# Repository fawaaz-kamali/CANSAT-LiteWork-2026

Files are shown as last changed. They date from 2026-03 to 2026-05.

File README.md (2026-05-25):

# CANSAT-LiteWork-2026
Repository containing major program files and schematics for Team 'Lite Work for the TMU CANSAT STEC Initiative 

Team Members: Fawaaz Kamali Siddiqui, Ben Reboks, Basim Allawala, Hamid Karimi, Mohammad Alwattar

## ESP32 Flight Computer

### Overview

The flight computer designed in the PDR phase of the competition is simply named the ESP32 Flight Computer. The circuit was designed 
entirely in KiCad and the microcontroller for the circuit is the ESP32-S3-WROOM-1. 

The parts list for this circuit is as follows:

| Model | Description |
|---|---|
| ESP32-S3-WROOM-1 | Microcontroller Unit |
| ICM-42670-L | Inertial Measurement Unit |
| ICP-20100 | Barometric Pressure Sensor |
| NEO-6M Breakout Board | GPS Module |
| 2 x SG90 | Servo Motors |
| 1S 18605 LiFePO4 | Battery |

#### KiCad Files
<div align="center">
  <div>
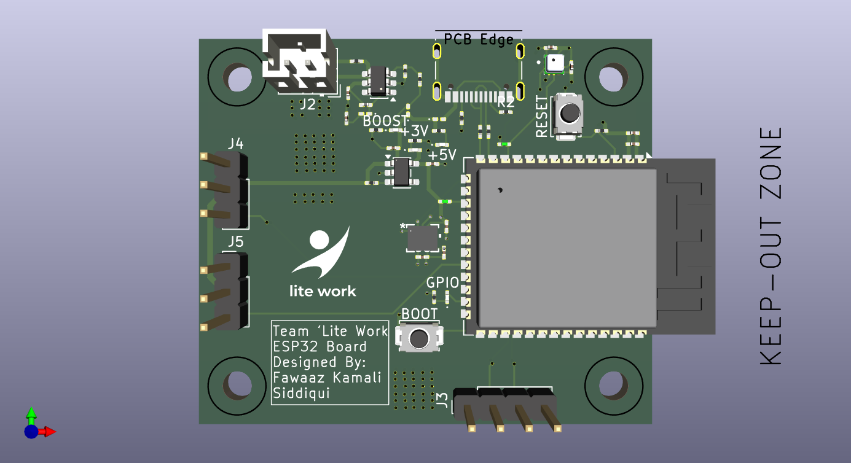
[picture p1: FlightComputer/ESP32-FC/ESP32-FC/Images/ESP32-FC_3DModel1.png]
    
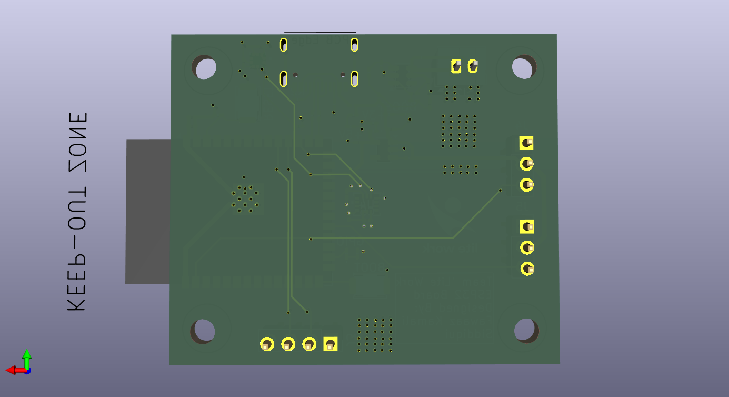
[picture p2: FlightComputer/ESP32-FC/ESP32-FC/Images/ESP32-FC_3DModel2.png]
    
    <p><em>3D Render</em></p>
  </div>
  <br>

  <div>
    Schematic<br>
    <p><em>Schematic</em></p>
  </div>
  <br>
  
  <div>
    Front
    Back<br>
    <em>Footprint</em>
  </div>
</div>

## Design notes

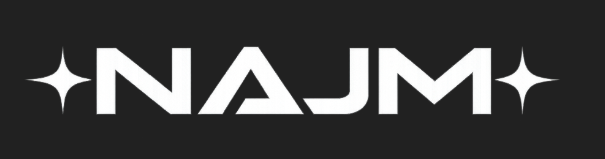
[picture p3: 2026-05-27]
FlightComputer/Arduino-FC/Arduino-FC/Images/Najm.png

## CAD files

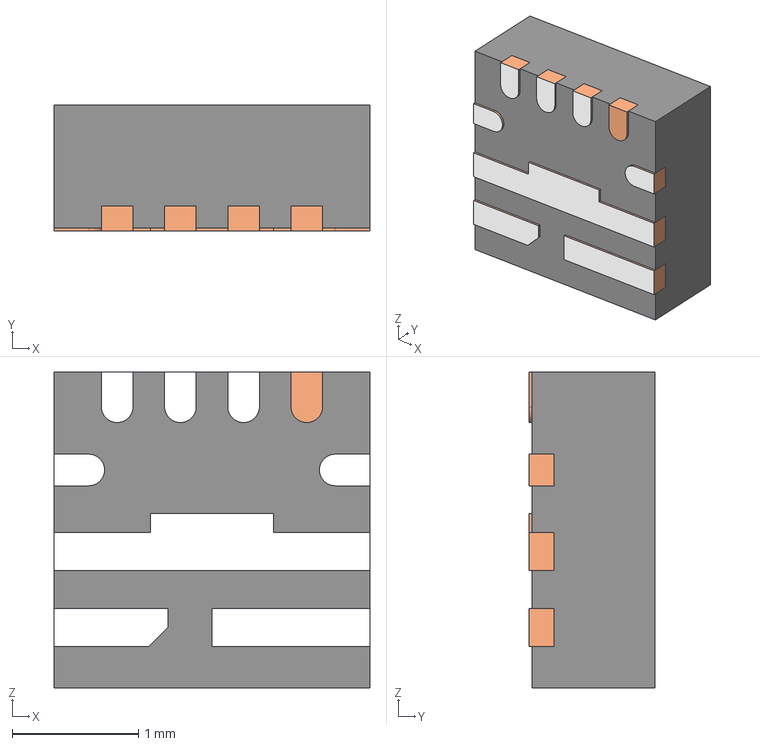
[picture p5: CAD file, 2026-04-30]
FlightComputer/Arduino-FC/Arduino-FC/TPS61236P/RWL0009A.stp
2.50 x 1.00 x 2.50 mm
FRAME-RWL0009A
BODY-QFN

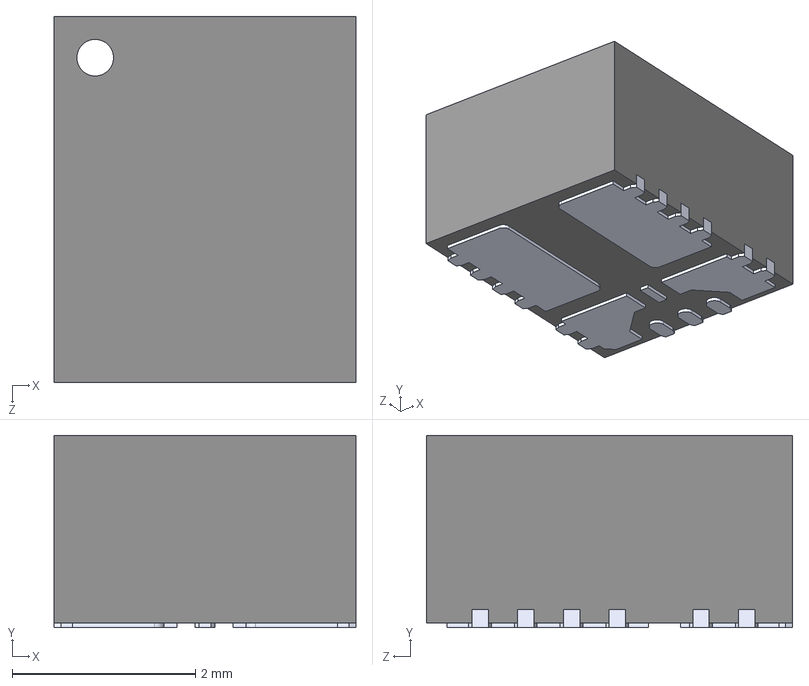
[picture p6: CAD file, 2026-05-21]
FlightComputer/Arduino-FC/Arduino-FC/TPSM863252RDXR/TPSM863252RDXR.step
3.30 x 2.10 x 4.00 mm

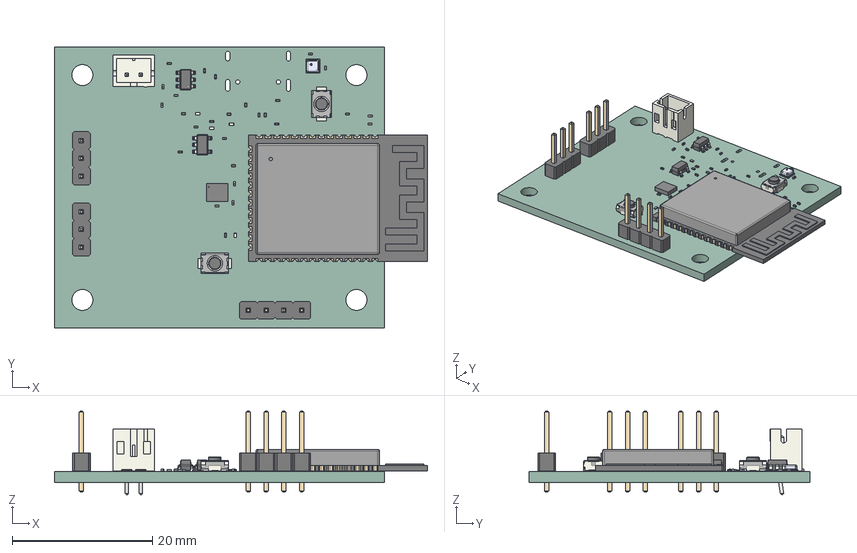
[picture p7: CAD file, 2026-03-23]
FlightComputer/ESP32-FC/ESP32-FC/ESP32-FC.step
53.2 x 40.0 x 11.9 mm
R_0201_0603Metric x 15
SW_Push_SPST_NO_Alps_SKRK x 2
LGA14_2_5X3X0_76_IVS
L_0201_0603Metric
C_0201_0603Metric x 11
ESP32-S3-WROOM-1
JST_PH_B2B-PH-K_1x02_P2.00mm_Vertical
LED_0201_0603Metric x 4
SOT-23-5
SOT-23-6
PinHeader_1x03_P2.54mm_Vertical x 2
ICP-20100
PinHeader_1x04_P2.54mm_Vertical
ESP32-FC_PCB

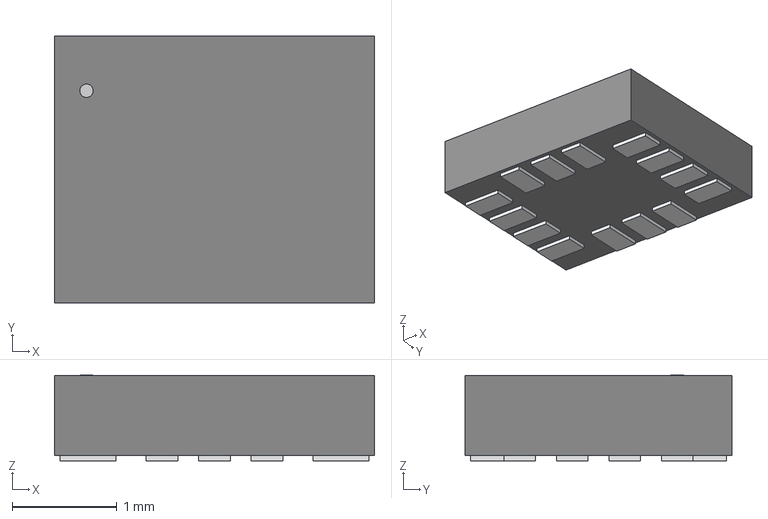
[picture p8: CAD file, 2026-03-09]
FlightComputer/ESP32-FC/ESP32-FC/ICM-42670-L/LGA14_2_5X3X0_76_IVS.step
3.05 x 2.54 x 0.815 mm

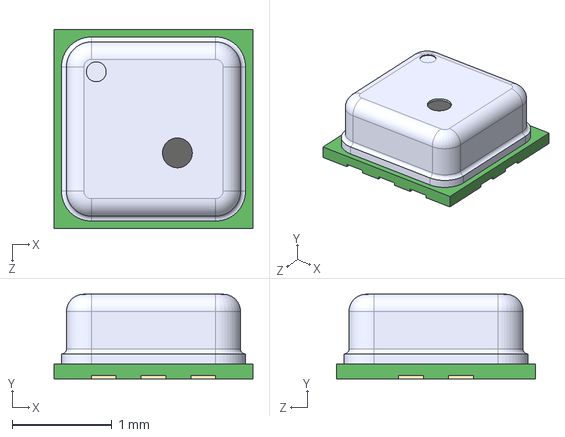
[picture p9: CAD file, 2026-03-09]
FlightComputer/ESP32-FC/ESP32-FC/ICP-20100/ICP-20100.step
2.00 x 0.85 x 2.00 mm

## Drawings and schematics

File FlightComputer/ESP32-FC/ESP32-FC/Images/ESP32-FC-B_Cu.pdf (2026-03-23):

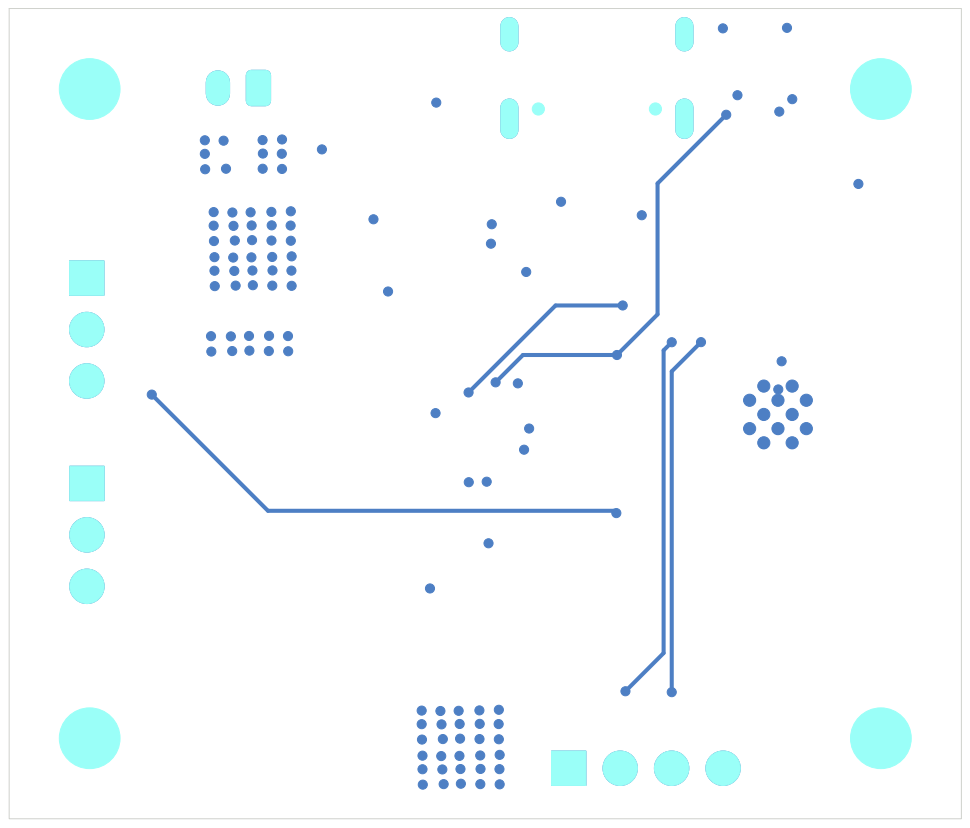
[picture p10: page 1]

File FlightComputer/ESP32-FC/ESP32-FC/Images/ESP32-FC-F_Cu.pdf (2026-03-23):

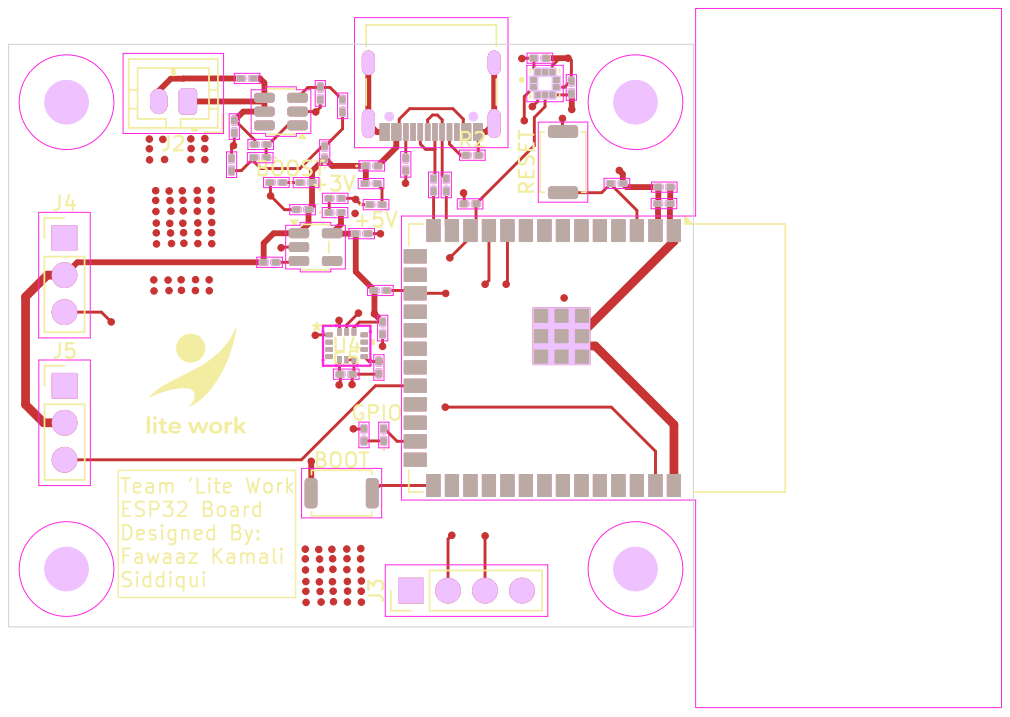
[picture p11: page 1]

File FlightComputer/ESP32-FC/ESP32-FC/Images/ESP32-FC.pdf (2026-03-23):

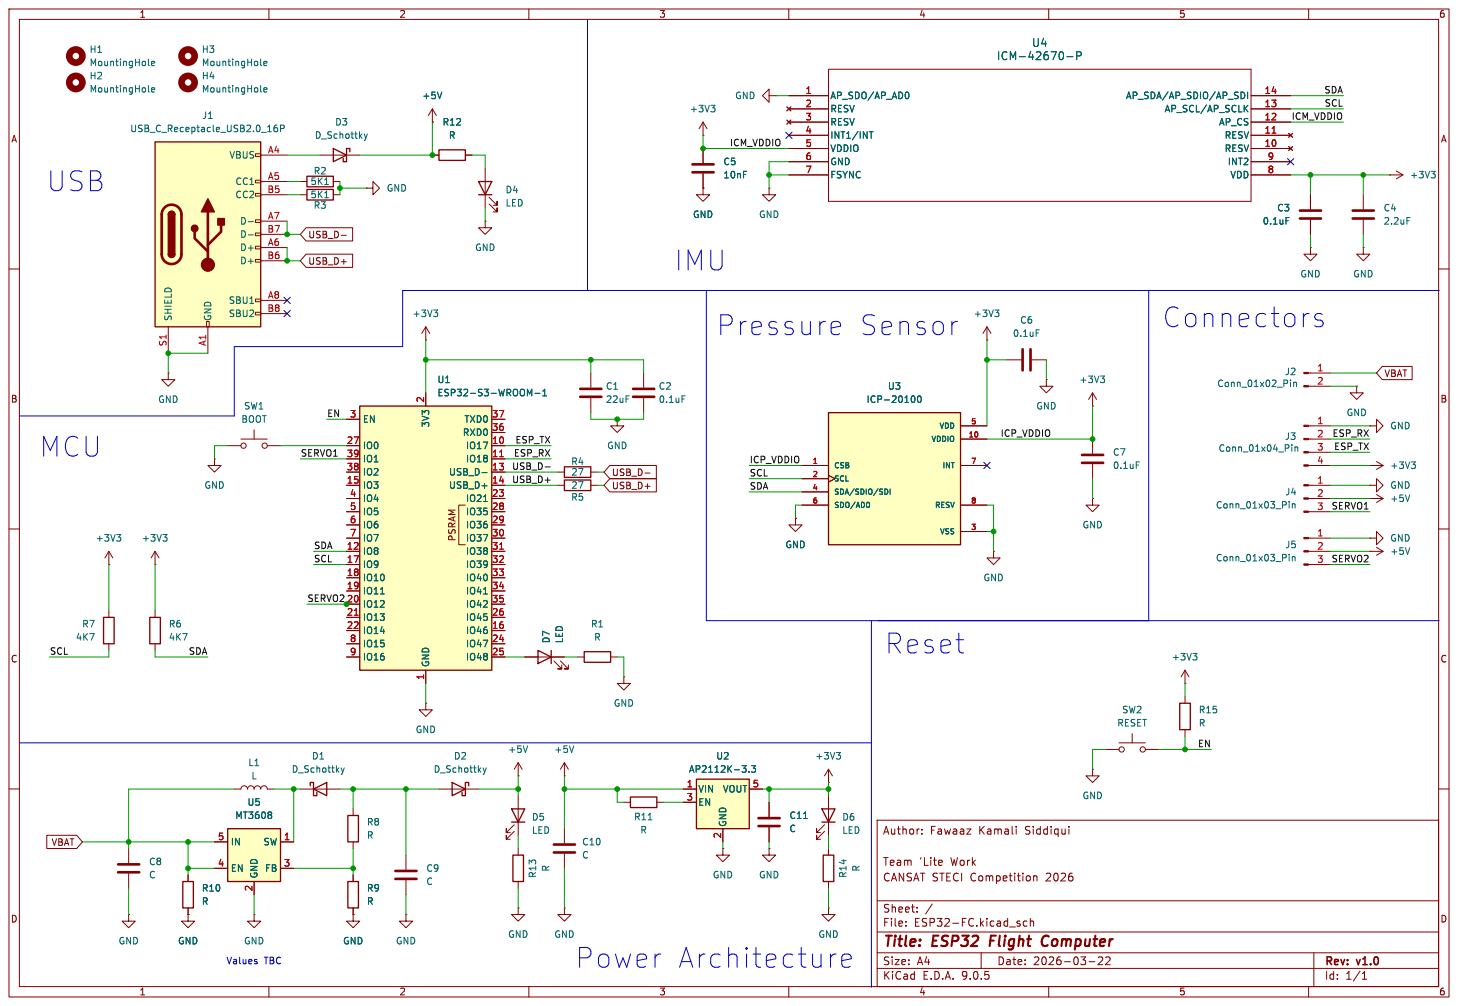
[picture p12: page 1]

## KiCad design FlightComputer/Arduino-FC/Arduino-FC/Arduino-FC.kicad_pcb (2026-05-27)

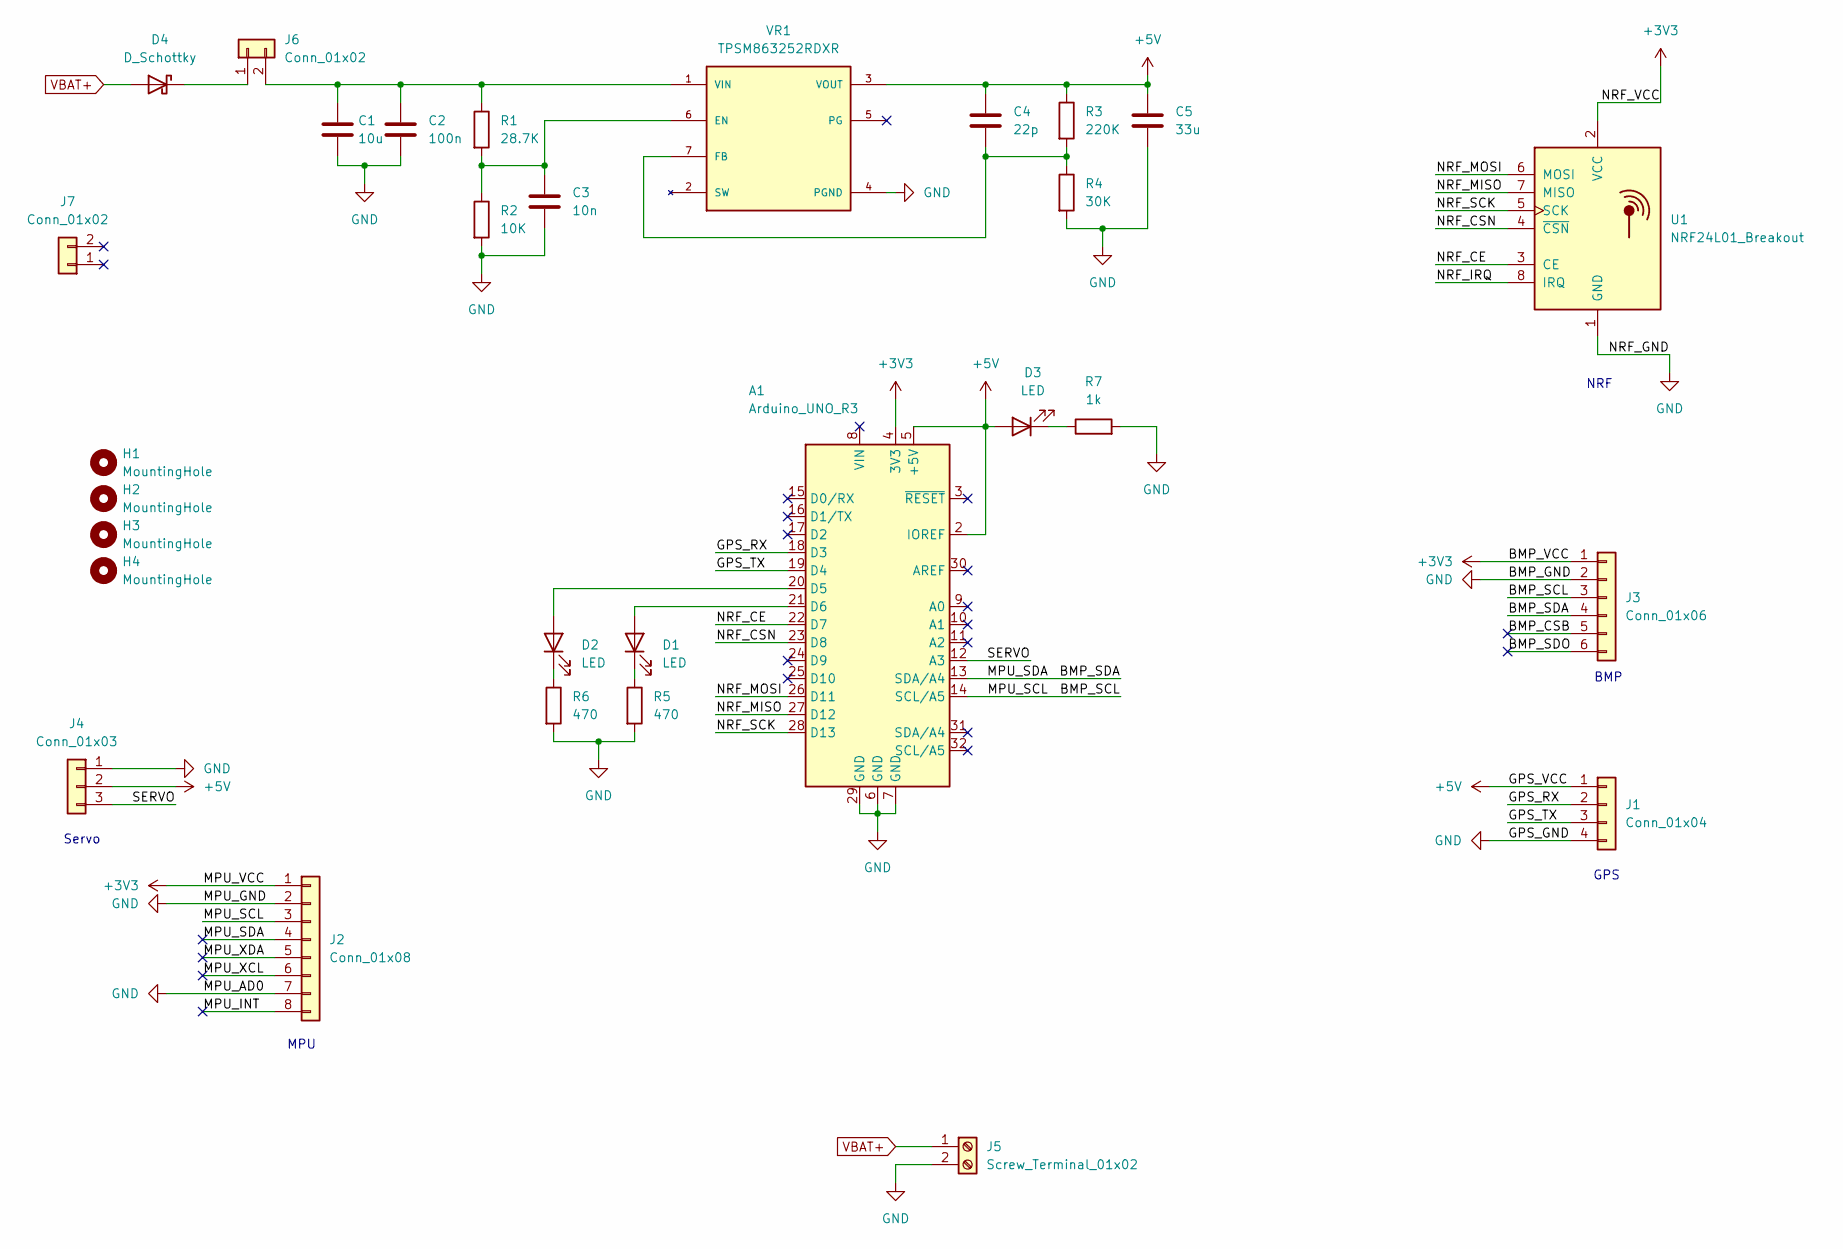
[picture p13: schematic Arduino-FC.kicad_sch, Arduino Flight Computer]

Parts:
A1: Arduino_UNO_R3
C1: 10u; C_0805_2012Metric_Pad1.18x1.45mm_HandSolder
C2: 100n; C_0805_2012Metric_Pad1.18x1.45mm_HandSolder
C3: 10n; C_0402_1005Metric_Pad0.74x0.62mm_HandSolder
C4: 22p; C_0402_1005Metric_Pad0.74x0.62mm_HandSolder
C5: 33u; C_1812_4532Metric_Pad1.57x3.40mm_HandSolder
D1, D2, D3: LED; LED_D5.0mm_Clear
D4: D_Schottky; DO-214AC
H1, H2, H3, H4: MountingHole; MountingHole_2.2mm_M2
J1: Conn_01x04; PinHeader_1x04_P2.54mm_Vertical
J2: Conn_01x08; PinHeader_1x08_P2.54mm_Vertical
J3: Conn_01x06; PinHeader_1x06_P2.54mm_Vertical
J4: Conn_01x03; PinHeader_1x03_P2.54mm_Vertical
J5: Screw_Terminal_01x02; TerminalBlock_MaiXu_MX126-5.0-02P_1x02_P5.00mm; LCSC C8465
J6, J7: Conn_01x02; PinHeader_1x02_P2.54mm_Vertical
R1: 28.7K; R_0402_1005Metric_Pad0.72x0.64mm_HandSolder
R2: 10K; R_0402_1005Metric_Pad0.72x0.64mm_HandSolder
R3: 220K; R_0603_1608Metric_Pad0.98x0.95mm_HandSolder
R4: 30K; R_0603_1608Metric_Pad0.98x0.95mm_HandSolder
R5, R6: 470; R_Axial_DIN0414_L11.9mm_D4.5mm_P15.24mm_Horizontal
R7: 1k; R_Axial_DIN0414_L11.9mm_D4.5mm_P15.24mm_Horizontal
U1: NRF24L01_Breakout; nRF24L01-Adapter
VR1: TPSM863252RDXR; VREG_TPSM863252RDXR; PARTREV B

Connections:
+3V3: A1.4 (3V3), J2.1, J3.1, U1.2 (VCC)
+5V: A1.2 (IOREF), A1.5 (+5V), C4.1, C5.1, D3.2 (A), J1.1, J4.2, R3.1, VR1.3 (VOUT)
/BMP_CSB: J3.5
/BMP_SCL: A1.14 (SCL/A5), J2.3, J3.3
/BMP_SDA: A1.13 (SDA/A4), J2.4, J3.4
/BMP_SDO: J3.6
/GPS_RX: A1.18 (D3), J1.2
/GPS_TX: A1.19 (D4), J1.3
/MPU_INT: J2.8
/MPU_XCL: J2.6
/MPU_XDA: J2.5
/NRF_CE: A1.22 (D7), U1.3 (CE)
/NRF_CSN: A1.23 (D8), U1.4 (~CSN)
/NRF_IRQ: U1.8 (IRQ)
/NRF_MISO: A1.27 (D12), U1.7 (MISO)
/NRF_MOSI: A1.26 (D11), U1.6 (MOSI)
/NRF_SCK: A1.28 (D13), U1.5 (SCK)
/SERVO: A1.12 (A3), J4.3
GND: A1.6 (GND), A1.7 (GND), A1.29 (GND), C1.2, C2.2, C3.2, C5.2, J1.4, J2.2, J2.7, J3.2, J4.1, J5.2, R2.2, R4.2, R5.2, R6.2, R7.2, U1.1 (GND), VR1.4 (PGND)
unnamed: A1.20 (D5), D2.2 (A)
unnamed: A1.21 (D6), D1.2 (A)
unnamed: D1.1 (K), R5.1
unnamed: D2.1 (K), R6.1
unnamed: D3.1 (K), R7.1
unnamed: D4.1 (K), J6.1
unnamed: C1.1, C2.1, J6.2, R1.1, VR1.1 (VIN)
unnamed: C3.1, R1.2, R2.1, VR1.6 (EN)
unnamed: C4.2, R3.2, R4.1, VR1.7 (FB)
VBAT+: D4.2 (A), J5.1

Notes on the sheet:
GPS
NRF
Servo
BMP
MPU

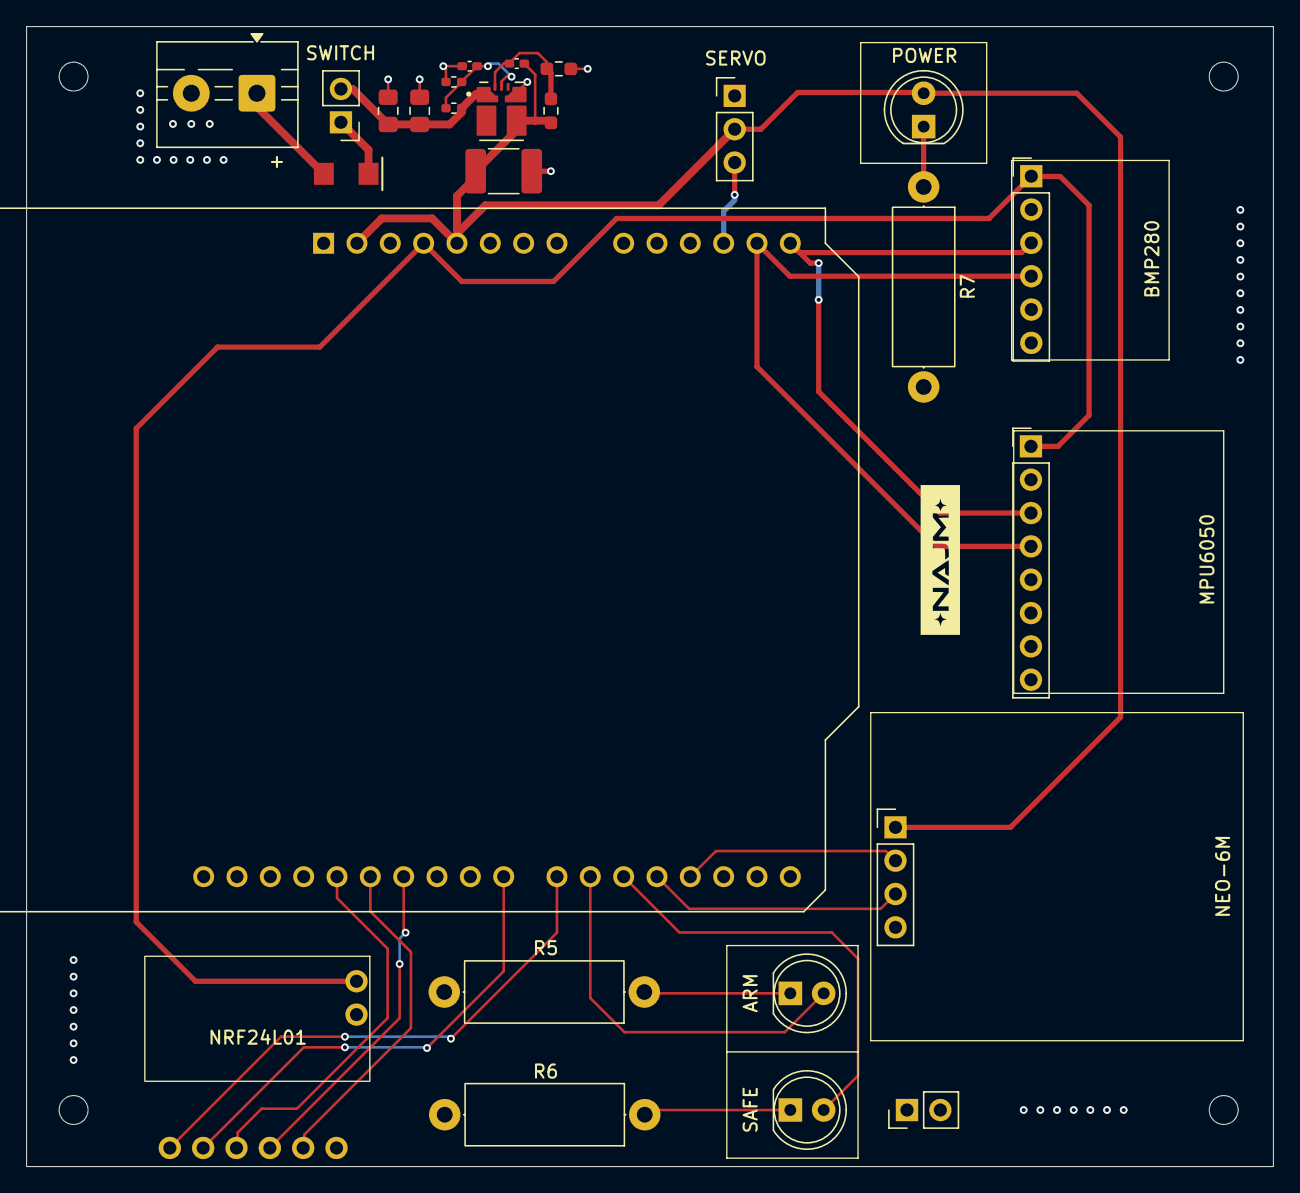
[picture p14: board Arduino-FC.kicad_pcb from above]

Board: 2 copper layers, 95.0 x 86.9 mm, 30 parts (0 on the bottom side), 23 nets.

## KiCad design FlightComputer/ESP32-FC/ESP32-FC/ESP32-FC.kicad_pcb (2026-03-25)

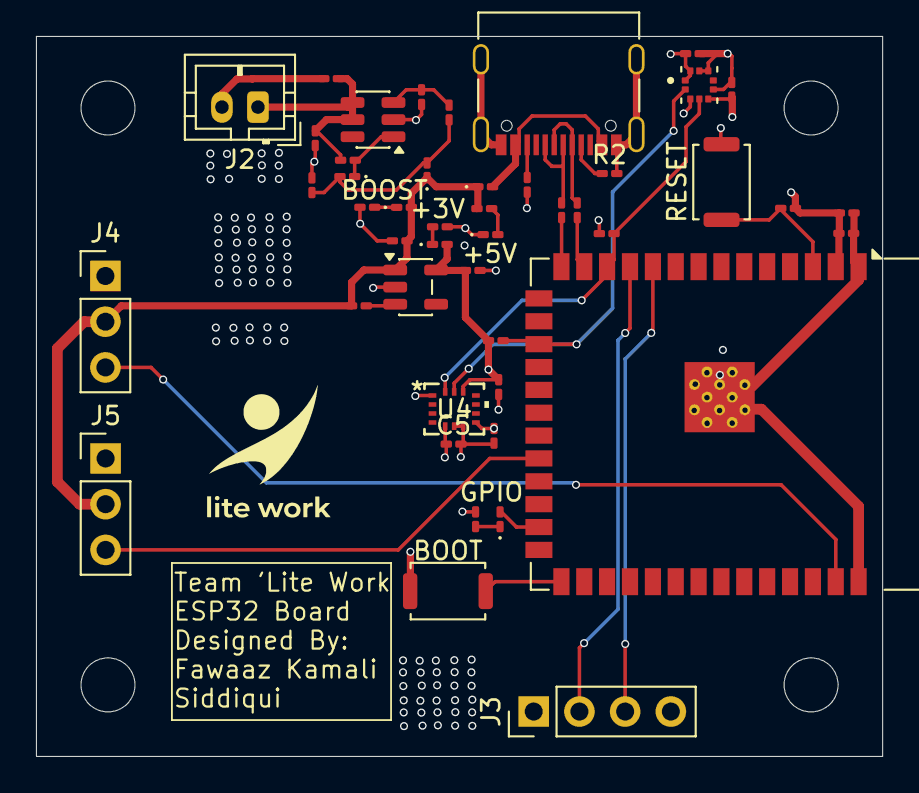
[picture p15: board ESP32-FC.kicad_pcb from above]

Board: 4 copper layers, 47.0 x 40.0 mm, 50 parts (0 on the bottom side), 26 nets.

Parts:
+3V, +5V: LED; LED_0201_0603Metric_Pad0.64x0.40mm_HandSolder
BOOST: LED; LED_0201_0603Metric_Pad0.64x0.40mm_HandSolder
BOOT: BOOT; SW_Push_SPST_NO_Alps_SKRK
C1: 22uF; C_0201_0603Metric_Pad0.64x0.40mm_HandSolder
C2, C3, C6, C7: 0.1uF; C_0201_0603Metric_Pad0.64x0.40mm_HandSolder
C4: 2.2uF; C_0201_0603Metric_Pad0.64x0.40mm_HandSolder
C5: 10nF; C_0201_0603Metric_Pad0.64x0.40mm_HandSolder
C8, C9, C10, C11: C; C_0201_0603Metric_Pad0.64x0.40mm_HandSolder
D1, D2, D3: D_Schottky; D_0201_0603Metric_Pad0.64x0.40mm_HandSolder
GPIO: LED; LED_0201_0603Metric_Pad0.64x0.40mm_HandSolder
H1, H2, H3, H4: MountingHole; MountingHole_3mm
J1: USB_C_Receptacle_USB2.0_16P; USB_C_Receptacle_Palconn_UTC16-G
J2: Conn_01x02_Pin; JST_PH_B2B-PH-K_1x02_P2.00mm_Vertical
J3: Conn_01x04_Pin; PinHeader_1x04_P2.54mm_Vertical
J4, J5: Conn_01x03_Pin; PinHeader_1x03_P2.54mm_Vertical
L1: L; L_0201_0603Metric_Pad0.64x0.40mm_HandSolder
R1, R8, R9, R10, R11, R12, R13, R14, R15: R; R_0201_0603Metric_Pad0.64x0.40mm_HandSolder
R2, R3: 5K1; R_0201_0603Metric_Pad0.64x0.40mm_HandSolder
R4, R5: 27; R_0201_0603Metric_Pad0.64x0.40mm_HandSolder
R6, R7: 4K7; R_0201_0603Metric_Pad0.64x0.40mm_HandSolder
RESET: RESET; SW_Push_SPST_NO_Alps_SKRK
U1: ESP32-S3-WROOM-1
U2: AP2112K-3.3; SOT-23-5
U3: ICP-20100; PQFN50P200X200X85-10N
U4: ICM-42670-P; LGA14_2.5X3X0.76_IVS-L
U5: MT3608; SOT-23-6

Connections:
+3V3: +3V.2 (A), C1.1, C2.1, C3.1, C4.1, C5.1, C6.2, C7.1, C11.1, J3.4, R6.1, R7.1, R15.1, U1.2 (3V3), U2.5 (VOUT), U3.1 (CSB), U3.5 (VDD), U3.10 (VDDIO), U4.5 (VDDIO), U4.8 (VDD), U4.12 (AP_CS)
+5V: BOOST.2 (A), C10.1, D2.1 (K), D3.1 (K), J4.2, J5.2, R11.1, R12.1, U2.1 (VIN)
/EN: R15.2, RESET.2, U1.3 (EN)
/ESP_RX: J3.2, U1.11 (IO18)
/ESP_TX: J3.3, U1.10 (IO17)
/SCL: R7.2, U1.17 (IO9), U3.2 (SCL), U4.13 (AP_SCL/AP_SCLK)
/SDA: R6.2, U1.12 (IO8), U3.4 (SDA/SDIO/SDI), U4.14 (AP_SDA/AP_SDIO/AP_SDI)
/SERVO1: J4.3, U1.39 (IO1)
/SERVO2: J5.3, U1.22 (IO14)
GND: +5V.1 (K), BOOT.1, C1.2, C2.2, C3.2, C4.2, C5.2, C6.1, C7.2, C8.2, C9.2, C10.2, C11.2, J1.A1 (GND), J1.A12 (GND), J1.B1 (GND), J1.B12 (GND), J1.S1 (SHIELD), J2.2, J3.1, J4.1, J5.1, R1.2, R2.2, R3.2, R9.2, R10.2, R13.1, R14.1, RESET.1, U1.1 (GND), U1.40 (GND), U1.41 (GND), U2.2 (GND), U3.3 (VSS), U3.6 (SDO/AD0), U3.8 (RESV), U3.9 (RESV), U4.1 (AP_SDO/AP_AD0), U4.6 (GND), U4.7 (FSYNC), U5.2 (GND)
unnamed: C9.1, D1.2 (A), D2.2 (A), R8.1
unnamed: D1.1 (K), L1.2, U5.1 (SW)
unnamed: D3.2 (A), J1.A4 (VBUS), J1.A9 (VBUS), J1.B4 (VBUS), J1.B9 (VBUS)
unnamed: +5V.2 (A), R12.2
unnamed: BOOST.1 (K), R13.2
unnamed: +3V.1 (K), R14.2
unnamed: GPIO.2 (A), U1.25 (IO48)
unnamed: GPIO.1 (K), R1.1
unnamed: J1.A5 (CC1), R2.1
unnamed: J1.B5 (CC2), R3.1
unnamed: BOOT.2, U1.27 (IO0)
unnamed: R11.2, U2.3 (EN)
unnamed: R8.2, R9.1, U5.3 (FB)
USB_D+: J1.A6 (D+), J1.B6 (D+), R5.1, R5.2, U1.14 (USB_D+)
USB_D-: J1.A7 (D-), J1.B7 (D-), R4.1, R4.2, U1.13 (USB_D-)
VBAT: C8.1, J2.1, L1.1, R10.1, U5.4 (EN), U5.5 (IN)

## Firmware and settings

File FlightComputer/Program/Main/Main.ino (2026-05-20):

/*
 * Rui Santos 
 * Complete Project Details https://randomnerdtutorials.com
 */
 
#include <SoftwareSerial.h>

// The serial connection to the GPS module
SoftwareSerial ss(4, 3);

void setup(){
  Serial.begin(9600);
  ss.begin(9600);
}

void loop(){
  while (ss.available() > 0){
    // get the byte data from the GPS
    byte gpsData = ss.read();
    Serial.write(gpsData);
  }
}

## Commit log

2026-03-08 Project Initialization
    [ESP32-FC.kicad_pcb, ESP32-FC.kicad_sch]
2026-03-08 Added USB Connection
    [ESP32-FC.kicad_sch]
2026-03-08 Added MPU
    [ESP32-FC.kicad_sch]
2026-03-09 Addd ICM
    - Removed MPU 6050
    - Added ICM-42670-P
    [ESP32-FC.kicad_sch, LGA14_2_5X3X0_76_IVS.step]
2026-03-09 Added ICP
    - Added pressure sensor module
    [ESP32-FC.kicad_sch, ICP-20100.step]
2026-03-19 Layout Creation
    [ESP32-FC.kicad_pcb, ESP32-FC.kicad_sch]
2026-03-22 Updated power architecture
    [ESP32-FC.kicad_sch]
2026-03-22 Servo + LEDs
    [ESP32-FC.kicad_sch]
2026-03-22 Boot Config
    [ESP32-FC.kicad_sch]
2026-03-22 Part placement
    [ESP32-FC.kicad_pcb, ESP32-FC.kicad_sch]
2026-03-23 Layout Major
    [ESP32-FC.kicad_pcb]
2026-03-23 Export STEP file
    [ESP32-FC.step]
2026-03-23 Update schematic
    [ESP32-FC.kicad_sch]
2026-03-23 Schematic Plot
2026-03-23 3D model images
    [ESP32-FC.kicad_pcb]
2026-03-23 Enhance README with PCB 3D model image
    TODO:
    > Add svg image of schematic and layout
2026-03-25 Added Images
    [ESP32-FC.kicad_pcb]
2026-03-25 Update README
    Added team members and detailed overview of the ESP32 Flight Computer, including parts list and KiCad files.
2026-04-30 Added second FC
    [Arduino-FC.kicad_pcb, Arduino-FC.kicad_sch, RWL0009A.stp]
2026-05-20 Added Main.ino
    Updated schematic connections
    [Arduino-FC.kicad_sch]
2026-05-21 Buck Converter
    Footprint assignments
    [Arduino-FC.kicad_sch, TPSM863252RDXR.step]
2026-05-24 Layout created
    [Arduino-FC.kicad_pcb]
2026-05-25 Custom NRF Adapter footprint
    [Arduino-FC.kicad_pcb, Arduino-FC.kicad_sch]
2026-05-25 Indicator LEDs + Screw terminal
    [Arduino-FC.kicad_pcb, Arduino-FC.kicad_sch]
2026-05-25 Added switch
    [Arduino-FC.kicad_pcb, Arduino-FC.kicad_sch]
2026-05-26 Buck Converter Updates
    - updated footprint + values
    [Arduino-FC.kicad_sch]
2026-05-26 Diode + Power Jumper
    [Arduino-FC.kicad_pcb, Arduino-FC.kicad_sch]
2026-05-26 Mounting Holes Added
    [Arduino-FC.kicad_pcb, Arduino-FC.kicad_sch]
2026-05-26 Design Constraints
    [Arduino-FC.kicad_pcb]
2026-05-26 Major Layout + Logo
    [Arduino-FC.kicad_pcb, Arduino-FC.kicad_sch]
2026-05-26 Background Slikscreen
    [Arduino-FC.kicad_pcb]
2026-05-26 updated resistor val
    [Arduino-FC.kicad_sch]
2026-05-26 Revert second logo
    [Arduino-FC.kicad_pcb]
2026-05-26 Revert "Major Layout + Logo"
    This reverts commit 6804596b28cb7cea65c62195238a1a9f434acbb5.
    [Arduino-FC.kicad_pcb, Arduino-FC.kicad_sch]
2026-05-26 Bottom Routing Complete
    [Arduino-FC.kicad_pcb]
2026-05-26 MPU + BMP Routing
    [Arduino-FC.kicad_pcb, Arduino-FC.kicad_sch]
2026-05-26 Buck Layout
    Update buck footprint
    [Arduino-FC.kicad_pcb]
2026-05-26 Complete Layout 1
    [Arduino-FC.kicad_pcb]
2026-05-27 Warnings Resolution
    [Arduino-FC.kicad_pcb]
2026-05-27 DRC Resolutions
    [Arduino-FC.kicad_pcb]
2026-05-27 Back Silkscreen Addition
    [Arduino-FC.kicad_pcb]
2026-05-27 Created Logo Footprint
2026-05-27 Added Najm Logo
    - Remade production files
    [Arduino-FC.kicad_pcb]
